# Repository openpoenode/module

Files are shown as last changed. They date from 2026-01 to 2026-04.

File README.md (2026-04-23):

# Technical Specifications

## Core Components

| Component | |
|---|---|
| MCU | ESP32-D0WD-V3 |
| Flash | Winbond SPI 128MBit W25Q128JVP |
| RAM | APMemory 64MBit APS6404L-3SQR-SN |
| Ethernet PHY | SMSC LAN8720A |
| PoE 802.3af Controller | TI TPS23753 |
| eFuse | TI TPS259520DSGR |

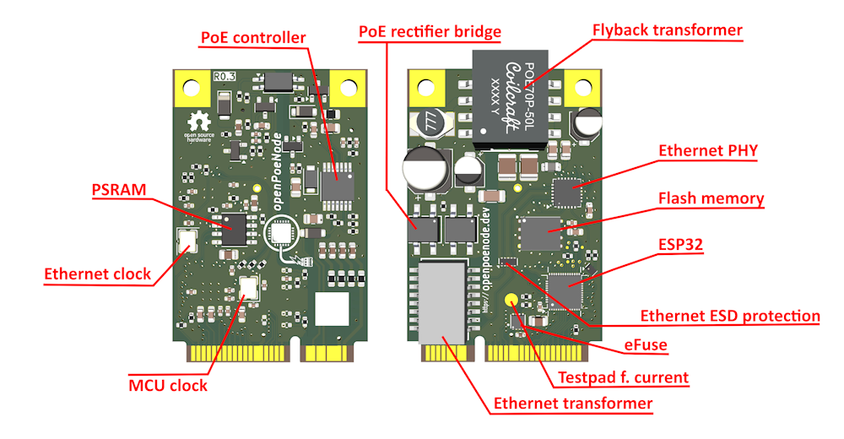
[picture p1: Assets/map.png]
ModuleMap


### Flash Memory

Any standard, pin-compatible SPI NOR flash in a WSON-8 6x5 mm package can be used. Common options are the 32MBit and 64MBit chips from the same line of Winbond flash memories.

### PSRAM

Installing a PSRAM chip is optional, the module will work just fine without the PSRAM IC populated. While any pin-compatible PSRAM chip can be installed, any amount over 32Mbit cannot be addressed by the ESP32 MCU.

### eFuse

- The digital power domain (MCU power supply input) is protected by a latch-off type eFuse. It disconnects supply at V<sub>in</sub> > 3.8V or I<sub>in</sub> > 1.04A.
- The module exposes a test pad for measuring the supply current drawn by the module's digital domain components:
  - I<sub>in</sub> = 1.81 x V<sub>test</sub>
  - V<sub>test</sub> is measured against digital ground

## Goldfinger Connector

The module exposes several signals of its components through a goldfinger connector:

### GPIOs

| GPIO | free | limited | input-only |
|---|---|---|---|
| 2 | | X | |
| 4 | | X | |
| 5 | | X | |
| 12 | | X | |
| 13 | X | | |
| 14 | X | | |
| 15 | | X | |
| 18 | X | | |
| 23 | X | | |
| 32 | X | | |
| 33 | X | | |
| 34 | | | X |
| 35 | | | X |
| 36 | | | X |
| 37 | | | X |
| 38 | | | X |
| 39 | | | X |

GPIOs marked as "limited" have a boot-strapping function and/or a fixed pull-up/pull-down in place.

3 output-capable GPIOs have to be assigned for Ethernet PHY control.

### Ethernet Interface

- Analog (2 differential data pairs, 2x center taps power input)
- 2 Indicator LEDs (Link/Activity, Speed)
- Bob-Smith-Termination
- Digital interface (Enable/Reset, MDC, MDIO)

### Power Supply / Conversion

- High Voltage (PoE domain)
  - External power adapter input, 36V < V<sub>in</sub> < 54V
  - Direct PoE power output for additional DC/DC converters (maximum power draw limited to 802.3af level)
- Low Voltage (Isolated domain)
  - DC/DC converter V<sub>out</sub> = 5V (3.3V optional)
  - I<sub>out,max</sub> = 1.4A (5V) or 2.1A (3.3V)
  - 7W max. output
- Digital domain
  - MCU power supply input (external 3.3V supply required)
  - I<sub>supply,avg</sub> < 500mA (soft limit)
  - I<sub>supply,lim</sub> = 1.04A (latch-off limit)
  - I<sub>supply,idle</sub> = ~150mA (idle supply current - including flash, RAM, 100MBit connected Ethernet, Link/Speed indicators on)

### Programming Interface

- ESP32 UART
- MCU Reset
- GPIO0 (boot strapping only, no direct connection)

## Physical

- Standard Mini-PCIe goldfinger connector, 52 pins
- FR4 1.00 mm base material, 6 layers
- Size: 45 x 30 x 14.5 mm
- Weight: 12g

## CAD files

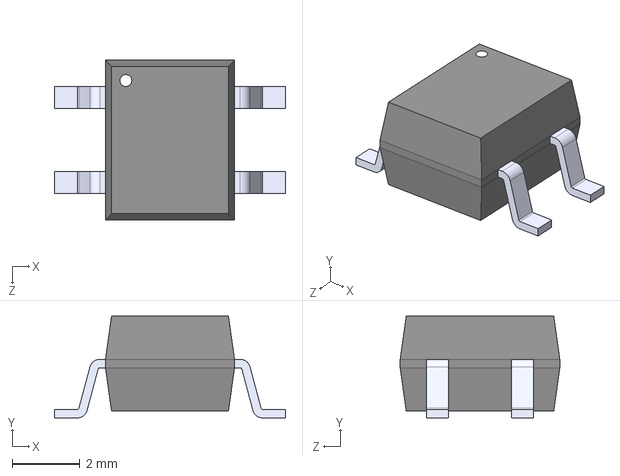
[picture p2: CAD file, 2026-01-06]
3D/HD01-T.STEP
6.80 x 3.00 x 4.70 mm

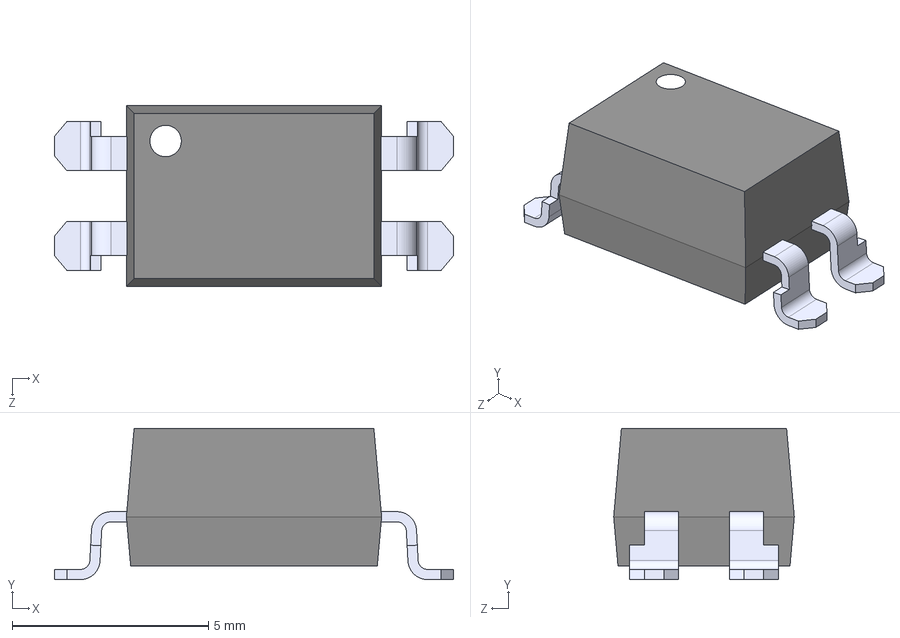
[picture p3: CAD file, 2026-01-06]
3D/FOD817AS.step
10.2 x 3.85 x 4.60 mm

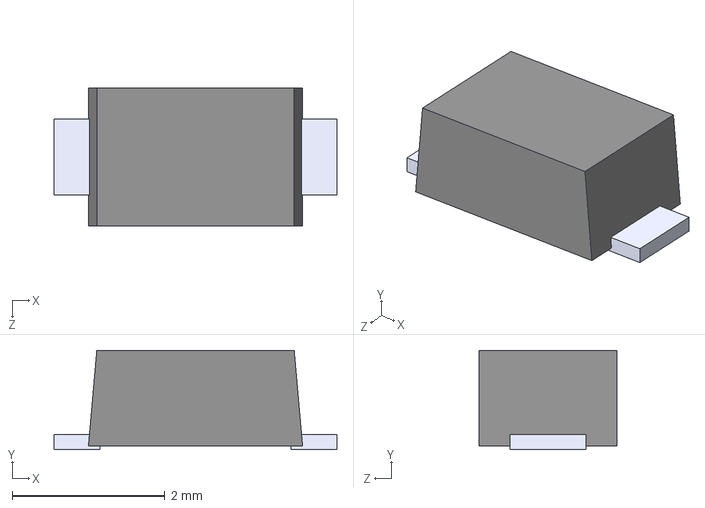
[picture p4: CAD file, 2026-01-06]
3D/USL1D.STEP
3.70 x 1.30 x 1.80 mm

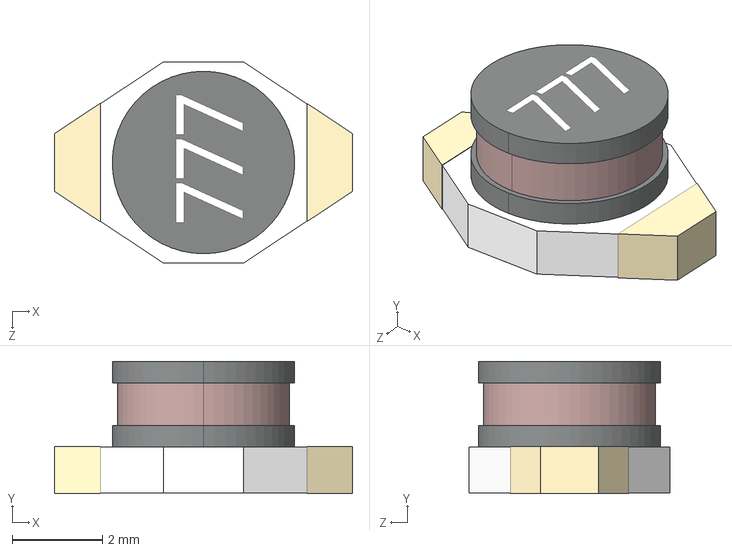
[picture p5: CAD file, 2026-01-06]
3D/Coilcraft-DO1608C.STEP
6.60 x 2.93 x 4.45 mm

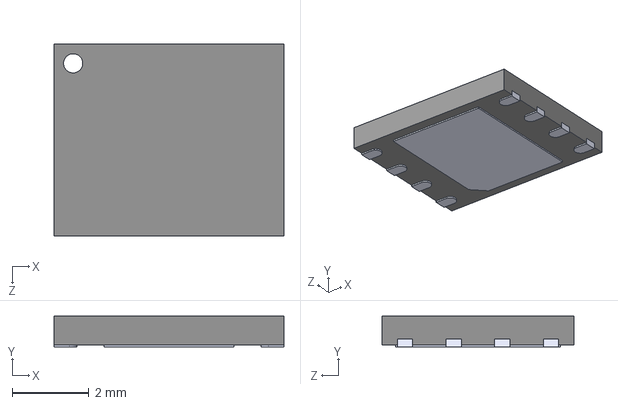
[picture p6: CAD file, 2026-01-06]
3D/W25Q32JVZPIQ.step
6.00 x 0.8 x 5.00 mm

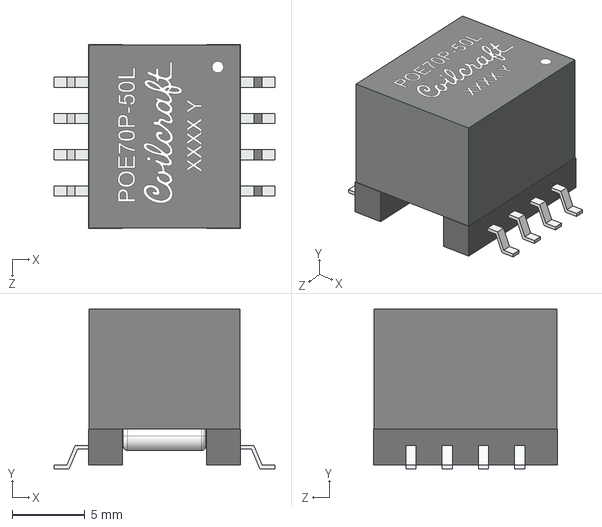
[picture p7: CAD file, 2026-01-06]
3D/Coilcraft-POE70P-50L.STEP
15.2 x 11.0 x 12.7 mm

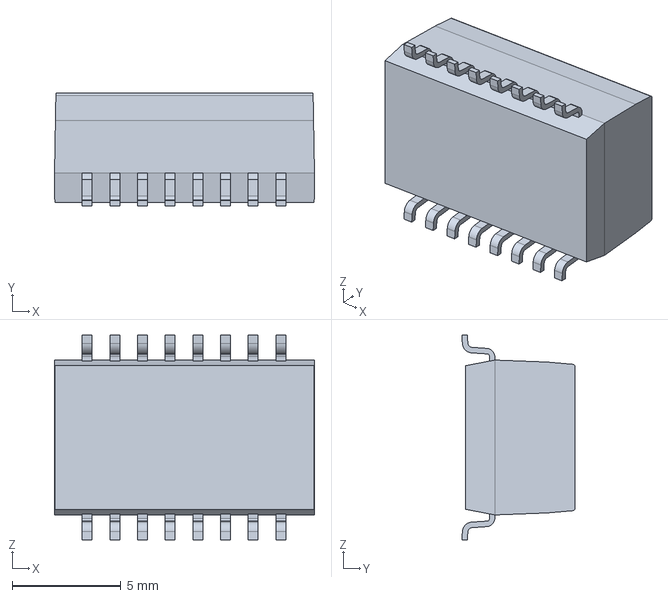
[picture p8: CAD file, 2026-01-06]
3D/S558-5500-25-F.stp
11.9 x 5.21 x 9.40 mm

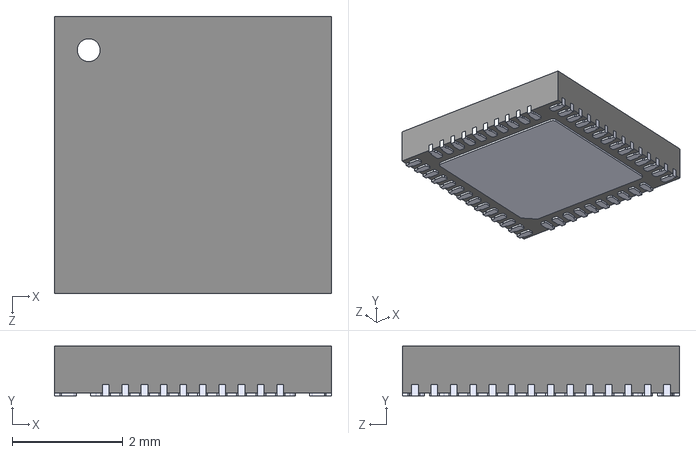
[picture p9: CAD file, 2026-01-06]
3D/ESP32-D0WD.step
5.00 x 0.9 x 5.00 mm

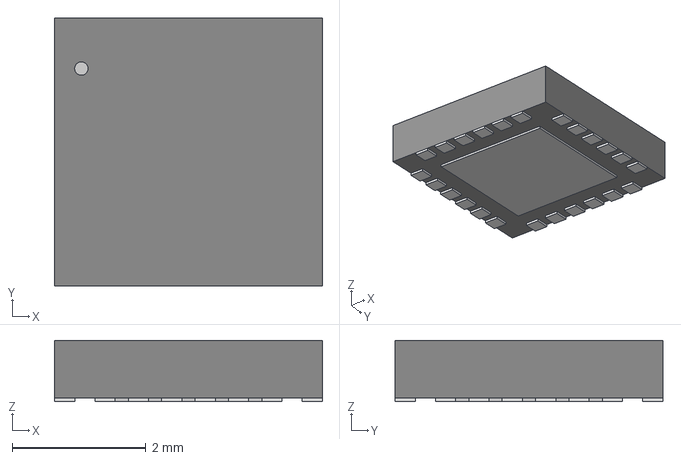
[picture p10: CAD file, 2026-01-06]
3D/QFN24-6X6_MC_MCH.step
4.01 x 4.01 x 0.917 mm

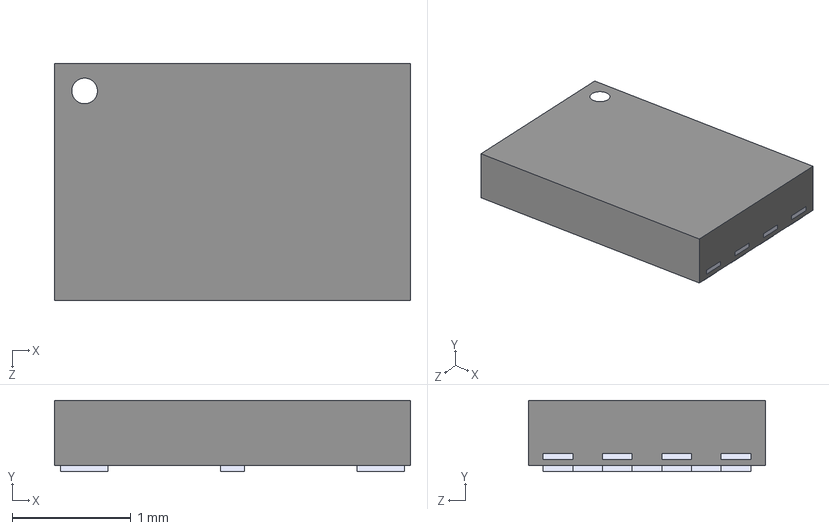
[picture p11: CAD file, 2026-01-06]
3D/USON8.STEP
3.00 x 0.6 x 2.00 mm

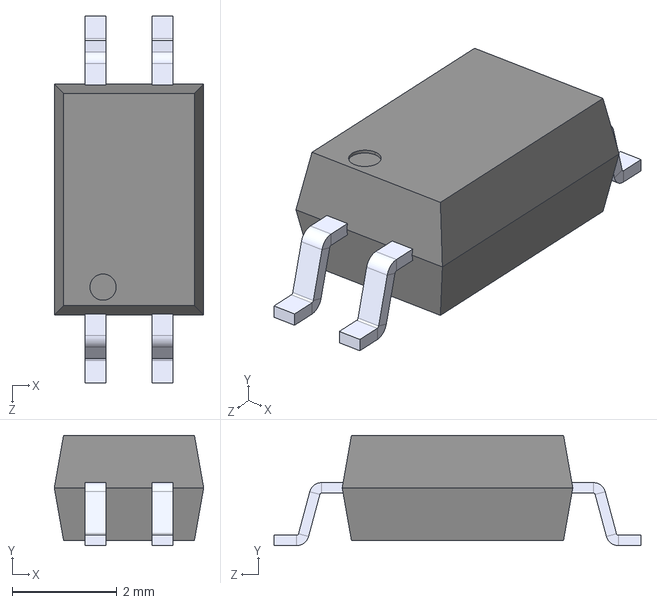
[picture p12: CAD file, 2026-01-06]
3D/VOS617A-8T.STEP
2.85 x 2.10 x 7.00 mm

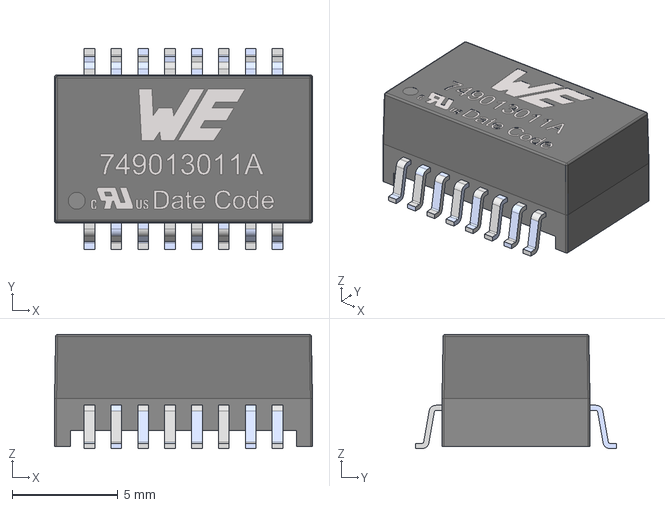
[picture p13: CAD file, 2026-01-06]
3D/749013011A.stp
12.2 x 9.52 x 5.40 mm
housing
Pin

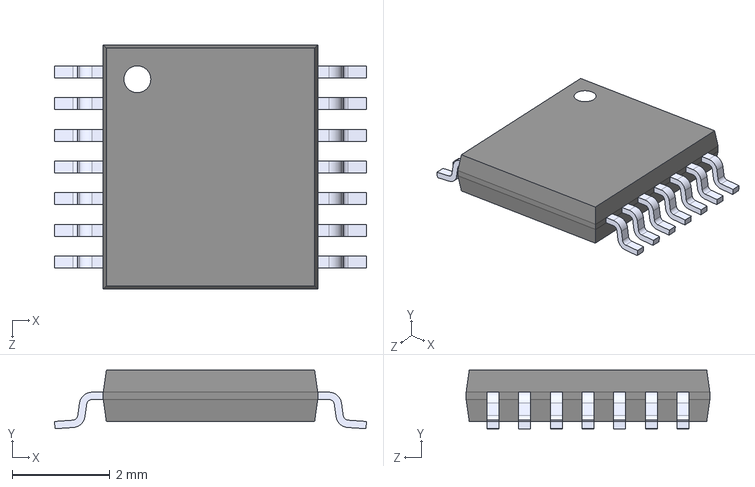
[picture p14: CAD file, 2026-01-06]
3D/TPS23753APW.step
6.40 x 1.20 x 5.00 mm

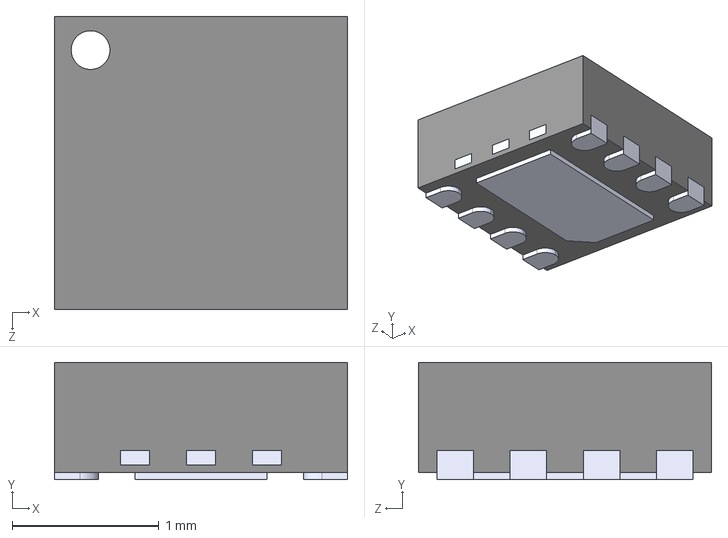
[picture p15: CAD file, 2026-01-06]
3D/TPS259520DSGR.step
2.00 x 0.8 x 2.00 mm

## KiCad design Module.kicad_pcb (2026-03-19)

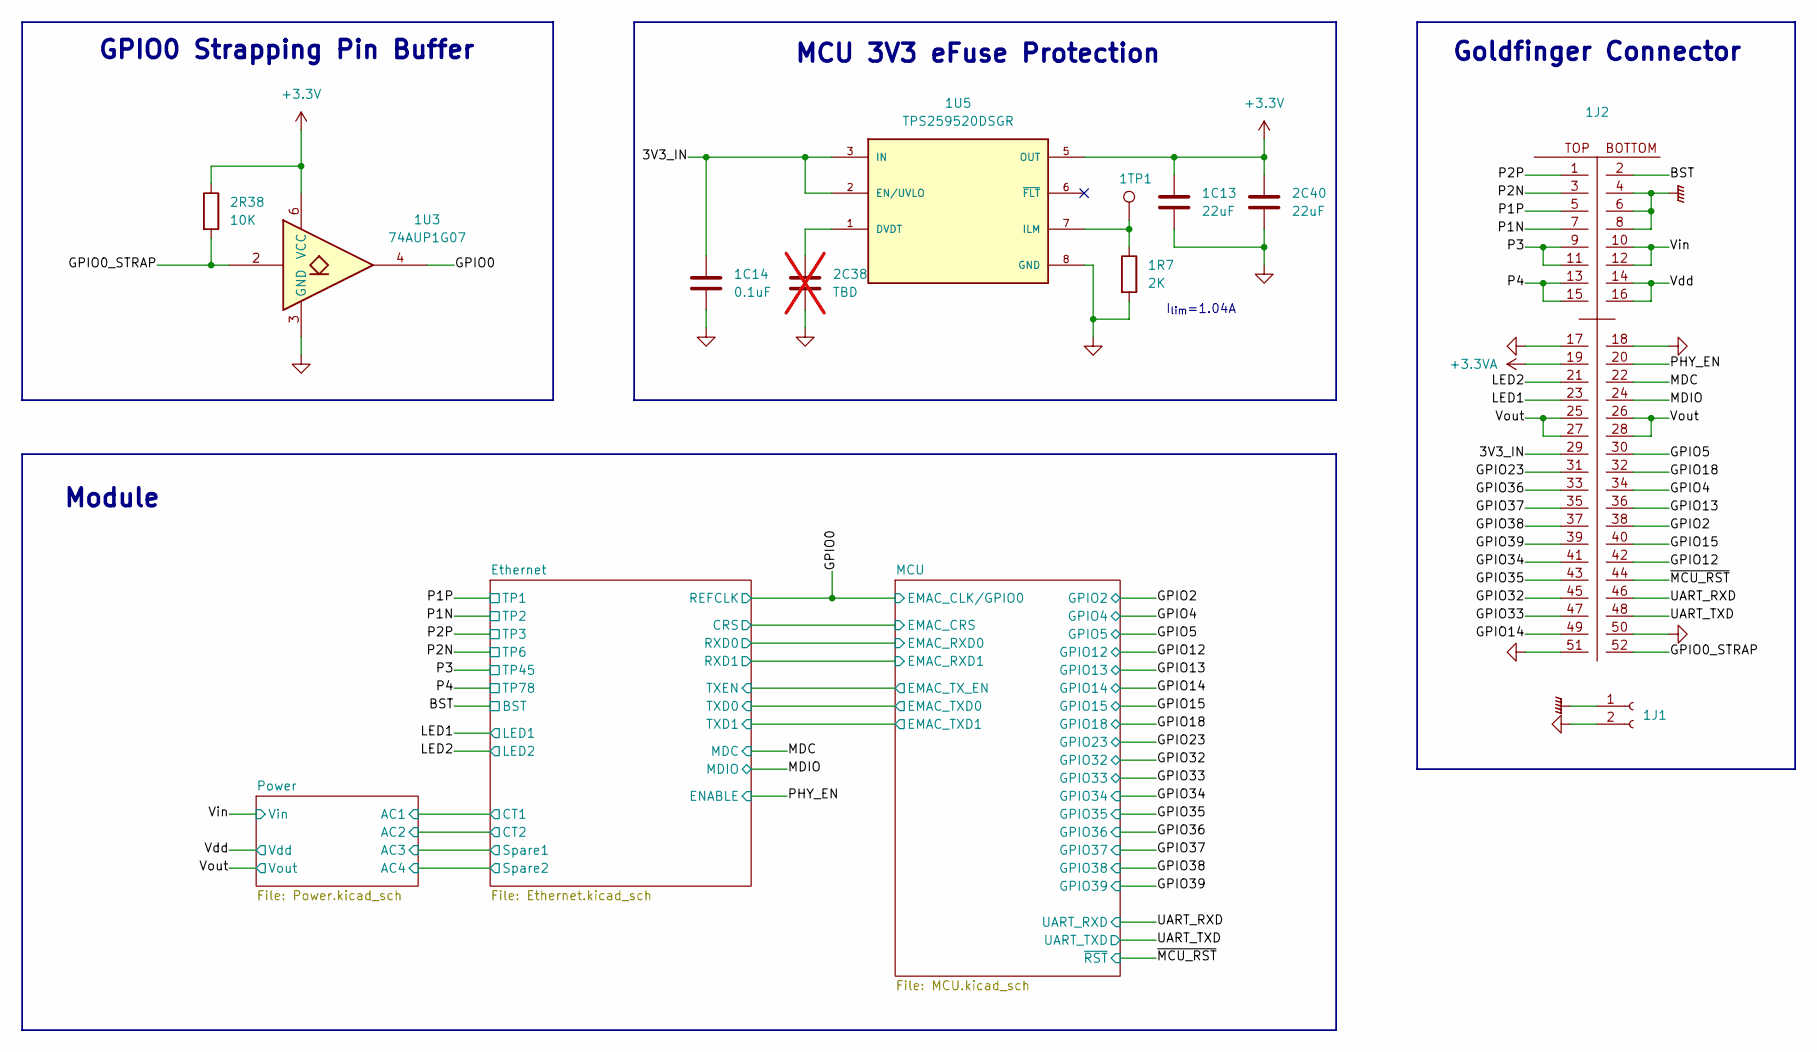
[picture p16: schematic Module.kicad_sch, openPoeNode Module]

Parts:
1C13, 2C40: 22uF; C_0805_2012Metric; MOUSER# 81-GRM21BZ71A226ME5L
1C14: 0.1uF; C_0402_1005Metric; MOUSER# 81-GCM155R71H104KE2J
1J1: HOLDDOWN; mPCIe-Hold
1J2: Mini-PCIe
1R7: 2K; R_0402_1005Metric; MOUSER# 71-CRCW0402-2.0K-E3
1TP1: TestPoint; TestPoint_Pad_D2.0mm
1U3: 74AUP1G07; Texas_USON-6_1x1.45mm_P0.5mm_SMD; MOUSER# 595-SN74AUP1G07DRYR
1U5: TPS259520DSGR; SON50P200X200X80-9N; MOUSER# 595-TPS259520DSGR
2C38: TBD; C_0402_1005Metric; not fitted
2R38: 10K; R_0402_1005Metric; MOUSER# 603-RE0402FRE0710KL

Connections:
+3.3V: 1C13.1, 1U3.6 (VCC), 1U5.5 (OUT), 2C40.1, 2R38.1; also elsewhere on the board
+3.3VA: 1J2.19; also elsewhere on the board
/3V3_IN: 1C14.2, 1J2.29, 1U5.2 (EN/UVLO), 1U5.3 (IN), 1U5.4 (IN)
/BST: 1J2.2; also elsewhere on the board
/GPIO0: 1U3.4; also elsewhere on the board
/GPIO0_STRAP: 1J2.52, 1U3.2, 2R38.2
/GPIO2: 1J2.38; also elsewhere on the board
/GPIO4: 1J2.34; also elsewhere on the board
/GPIO5: 1J2.30; also elsewhere on the board
/GPIO12: 1J2.42; also elsewhere on the board
/GPIO13: 1J2.36; also elsewhere on the board
/GPIO14: 1J2.49; also elsewhere on the board
/GPIO15: 1J2.40; also elsewhere on the board
/GPIO18: 1J2.32; also elsewhere on the board
/GPIO23: 1J2.31; also elsewhere on the board
/GPIO32: 1J2.45; also elsewhere on the board
/GPIO33: 1J2.47; also elsewhere on the board
/GPIO34: 1J2.41; also elsewhere on the board
/GPIO35: 1J2.43; also elsewhere on the board
/GPIO36: 1J2.33; also elsewhere on the board
/GPIO37: 1J2.35; also elsewhere on the board
/GPIO38: 1J2.37; also elsewhere on the board
/GPIO39: 1J2.39; also elsewhere on the board
/LED1: 1J2.23; also elsewhere on the board
/LED2: 1J2.21; also elsewhere on the board
/MDC: 1J2.22; also elsewhere on the board
/MDIO: 1J2.24; also elsewhere on the board
/P1N: 1J2.7; also elsewhere on the board
/P1P: 1J2.5; also elsewhere on the board
/P2N: 1J2.3; also elsewhere on the board
/P2P: 1J2.1; also elsewhere on the board
/P3: 1J2.9, 1J2.11; also elsewhere on the board
/P4: 1J2.13, 1J2.15; also elsewhere on the board
/PHY_EN: 1J2.20; also elsewhere on the board
/UART_RXD: 1J2.46; also elsewhere on the board
/UART_TXD: 1J2.48; also elsewhere on the board
/Vdd: 1J2.14, 1J2.16; also elsewhere on the board
/Vin: 1J2.10, 1J2.12; also elsewhere on the board
/Vout: 1J2.25, 1J2.26, 1J2.27, 1J2.28; also elsewhere on the board
/~MCU_RST: 1J2.44; also elsewhere on the board
GND: 1C13.2, 1C14.1, 1J1.2, 1J2.17, 1J2.18, 1J2.50, 1J2.51, 1R7.2, 1U3.3 (GND), 1U5.8 (GND), 1U5.9 (GND), 2C38.2, 2C40.2; also elsewhere on the board
GNDPWR: 1J1.1, 1J2.4, 1J2.6, 1J2.8; also elsewhere on the board
unnamed: 1U5.1 (DVDT), 2C38.1
unnamed: 1R7.1, 1TP1.1, 1U5.7 (ILM)

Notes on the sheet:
Goldfinger Connector
I_{lim}=1.04A
MCU 3V3 eFuse Protection
GPIO0 Strapping Pin Buffer
Module

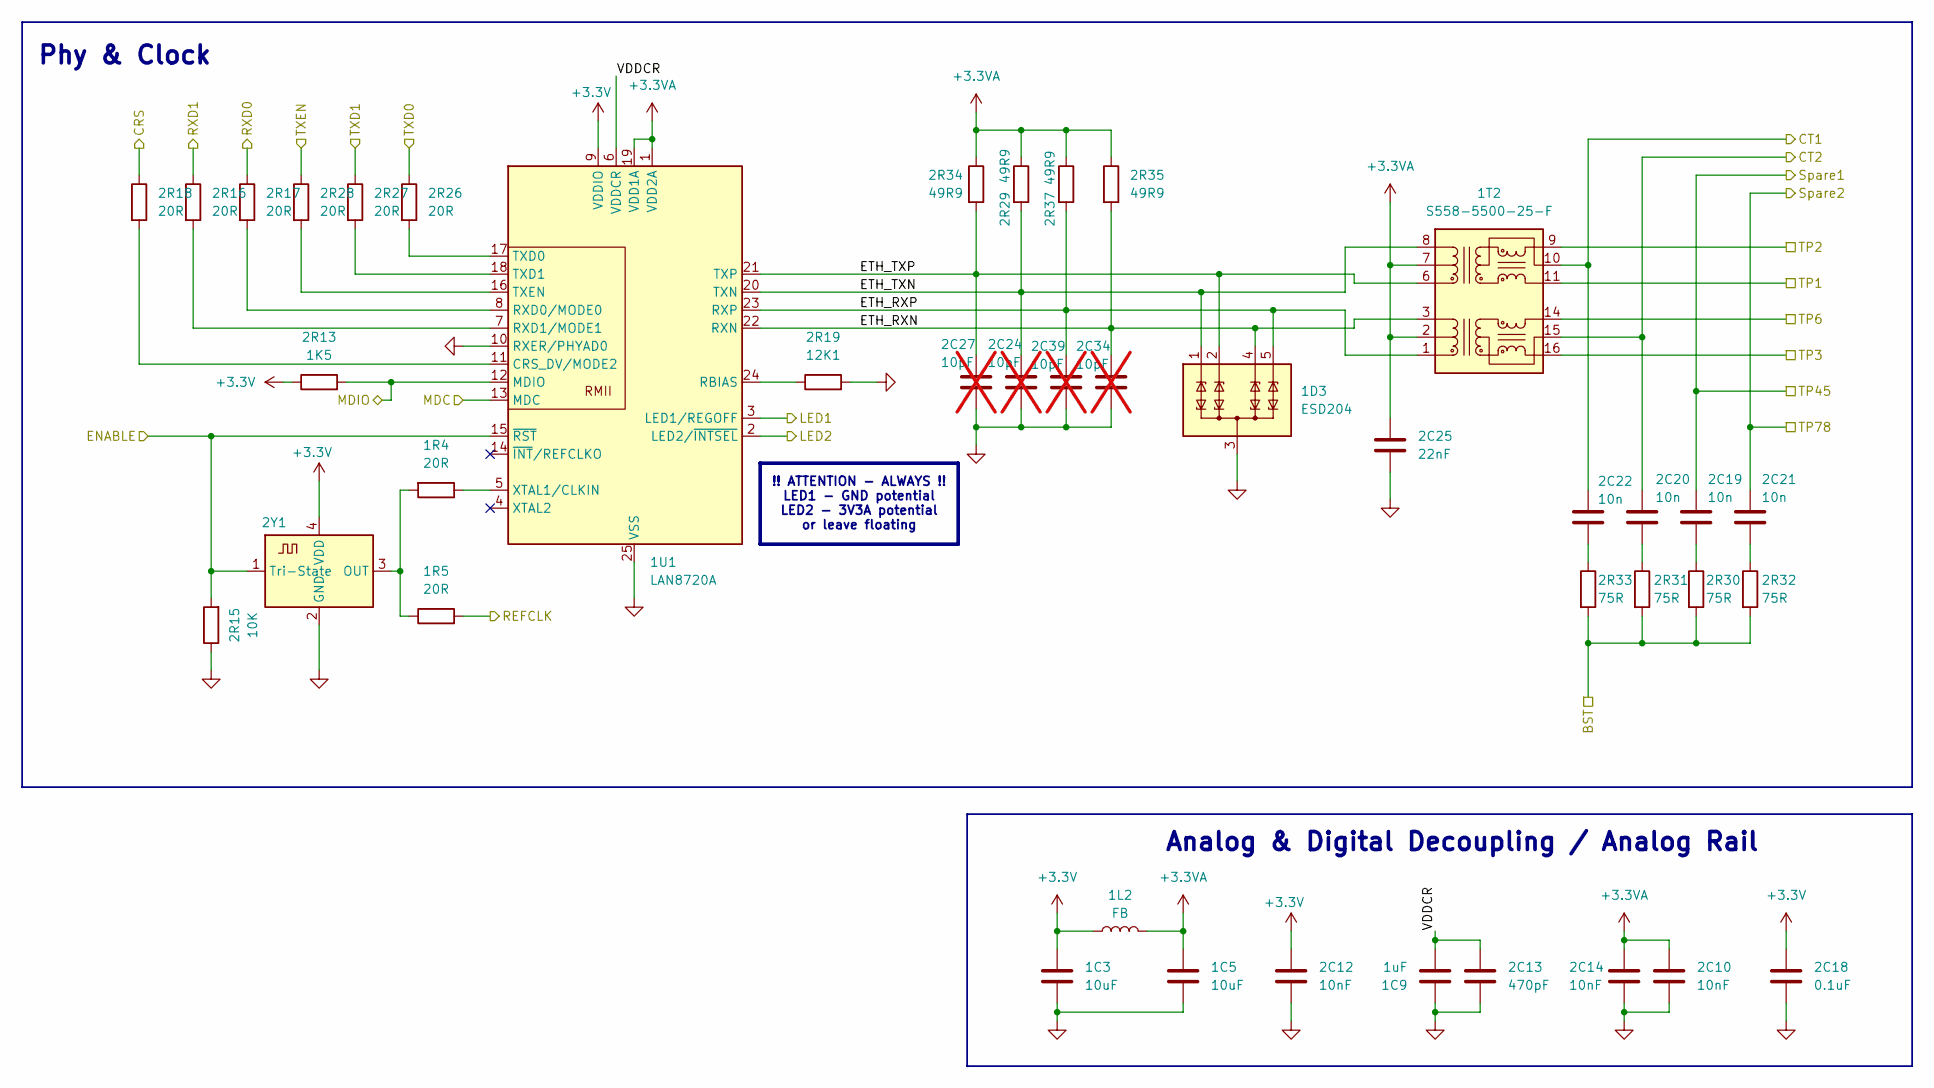
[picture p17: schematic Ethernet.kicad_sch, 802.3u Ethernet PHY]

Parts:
1C3, 1C5: 10uF; C_0805_2012Metric; MOUSER# 81-GRM21BR71A106MA3L
1C9: 1uF; C_0603_1608Metric; MOUSER# 963-EMK107B7105KA-T
1D3: ESD204; USON-10_2.5x1.0mm_P0.5mm; MOUSER# 595-ESD204DQAR
1L2: FB; L_0805_2012Metric; MOUSER#(alt) 603-BBPY201209121Y00
1R4, 1R5, 2R16, 2R17, 2R18, 2R26, 2R27, 2R28: 20R; R_0402_1005Metric; MOUSER# 660-RK73B1ETTP200J
1T2: S558-5500-25-F; MOUSER# 530-S558-5500-25-F
1U1: LAN8720A; QFN-24-1EP_4x4mm_P0.5mm_EP2.5x2.5mm; MOUSER# 579-LAN8720ACPTRABC
2C10, 2C12, 2C14: 10nF; C_0402_1005Metric; MOUSER# 963-EMK105B7103KV-F
2C13: 470pF; C_0402_1005Metric; MOUSER# 791-0402B471K250CT
2C18: 0.1uF; C_0402_1005Metric; MOUSER# 81-GCM155R71H104KE2J
2C19, 2C20, 2C21, 2C22: 10n; C_0603_1608Metric; MOUSER# 603-CC0603JRX70BB103
2C24, 2C27, 2C34, 2C39: 10pF; C_0402_1005Metric; MOUSER# 963-UMK105CG100DV-F; not fitted
2C25: 22nF; C_0402_1005Metric; MOUSER# 81-GRM155R71H223KA2J
2R13: 1K5; R_0402_1005Metric; MOUSER# 667-ERJ-2RKF1501X
2R15: 10K; R_0402_1005Metric; MOUSER# 603-RE0402FRE0710KL
2R19: 12K1; R_0402_1005Metric; MOUSER# 603-RT0402FRE0712K1L
2R29, 2R34, 2R35, 2R37: 49R9; R_0402_1005Metric; MOUSER# 660-RK73H1ETTP49R9F
2R30, 2R31, 2R32, 2R33: 75R; R_0603_1608Metric; MOUSER# 660-SG73S1JTTD75R0F
2Y1: ECS-2333-500-BN-TR; Crystal_SMD_3225-4Pin_3.2x2.5mm; MOUSER# 520-ECS-2333-500-BNT

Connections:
+3.3V: 1C3.1, 1L2.1, 1U1.9 (VDDIO), 2C12.2, 2C18.2, 2R13.1, 2Y1.4 (VDD); also elsewhere on the board
+3.3VA: 1C5.1, 1L2.2, 1T2.2 (C_TD), 1T2.7 (C_RD), 1U1.1 (VDD2A), 1U1.19 (VDD1A), 2C10.2, 2C14.2, 2C25.1, 2R29.1, 2R34.1, 2R35.1, 2R37.1; also elsewhere on the board
/BST: 2R30.2, 2R31.2, 2R32.2, 2R33.2; also elsewhere on the board
/Ethernet/CRS: 2R18.1; also elsewhere on the board
/Ethernet/CT1: 1T2.10 (C_RX), 2C22.1; also elsewhere on the board
/Ethernet/CT2: 1T2.15 (C_TX), 2C20.1; also elsewhere on the board
/Ethernet/ETH_RXN: 1D3.4 (TVS3), 1D3.7 (TVS3), 1T2.3 (TD-), 1U1.22 (RXN), 2C34.1, 2R35.2
/Ethernet/ETH_RXP: 1D3.5 (TVS4), 1D3.6 (TVS4), 1T2.1 (TD+), 1U1.23 (RXP), 2C39.1, 2R37.2
/Ethernet/ETH_TXN: 1D3.1 (TVS1), 1D3.10 (TVS1), 1T2.8 (RD-), 1U1.20 (TXN), 2C24.1, 2R29.2
/Ethernet/ETH_TXP: 1D3.2 (TVS2), 1D3.9 (TVS2), 1T2.6 (RD+), 1U1.21 (TXP), 2C27.1, 2R34.2
/Ethernet/RXD0: 2R17.1; also elsewhere on the board
/Ethernet/RXD1: 2R16.1; also elsewhere on the board
/Ethernet/TXD0: 2R26.1; also elsewhere on the board
/Ethernet/TXD1: 2R27.1; also elsewhere on the board
/Ethernet/TXEN: 2R28.1; also elsewhere on the board
/Ethernet/VDDCR: 1C9.1, 1U1.6 (VDDCR), 2C13.1
/GPIO0: 1R5.2; also elsewhere on the board
/LED1: 1U1.3 (LED1/REGOFF); also elsewhere on the board
/LED2: 1U1.2 (LED2/~INTSEL); also elsewhere on the board
/MDC: 1U1.13 (MDC); also elsewhere on the board
/MDIO: 1U1.12 (MDIO), 2R13.2; also elsewhere on the board
/P1N: 1T2.9 (RX-); also elsewhere on the board
/P1P: 1T2.11 (RX+); also elsewhere on the board
/P2N: 1T2.14 (TX-); also elsewhere on the board
/P2P: 1T2.16 (TX+); also elsewhere on the board
/P3: 2C19.1; also elsewhere on the board
/P4: 2C21.1; also elsewhere on the board
/PHY_EN: 1U1.15 (~RST), 2R15.2, 2Y1.1 (Tri-State); also elsewhere on the board
GND: 1C3.2, 1C5.2, 1C9.2, 1D3.3 (COM), 1D3.8 (COM), 1U1.10 (RXER/PHYAD0), 1U1.25 (VSS), 2C10.1, 2C12.1, 2C13.2, 2C14.1, 2C18.1, 2C24.2, 2C25.2, 2C27.2, 2C34.2, 2C39.2, 2R15.1, 2R19.2, 2Y1.2 (GND); also elsewhere on the board
unnamed: 1U1.11 (CRS_DV/MODE2), 2R18.2
unnamed: 1U1.24 (RBIAS), 2R19.1
unnamed: 1U1.8 (RXD0/MODE0), 2R17.2
unnamed: 1U1.7 (RXD1/MODE1), 2R16.2
unnamed: 1U1.17 (TXD0), 2R26.2
unnamed: 1U1.18 (TXD1), 2R27.2
unnamed: 1U1.16 (TXEN), 2R28.2
unnamed: 1R4.1, 1U1.5 (XTAL1/CLKIN)
unnamed: 2C19.2, 2R30.1
unnamed: 2C20.2, 2R31.1
unnamed: 2C21.2, 2R32.1
unnamed: 2C22.2, 2R33.1
unnamed: 1R4.2, 1R5.1, 2Y1.3 (OUT)

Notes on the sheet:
Phy & Clock
!! ATTENTION - ALWAYS !! LED1 - GND potential LED2 - 3V3A potential or leave floating
Analog & Digital Decoupling / Analog Rail

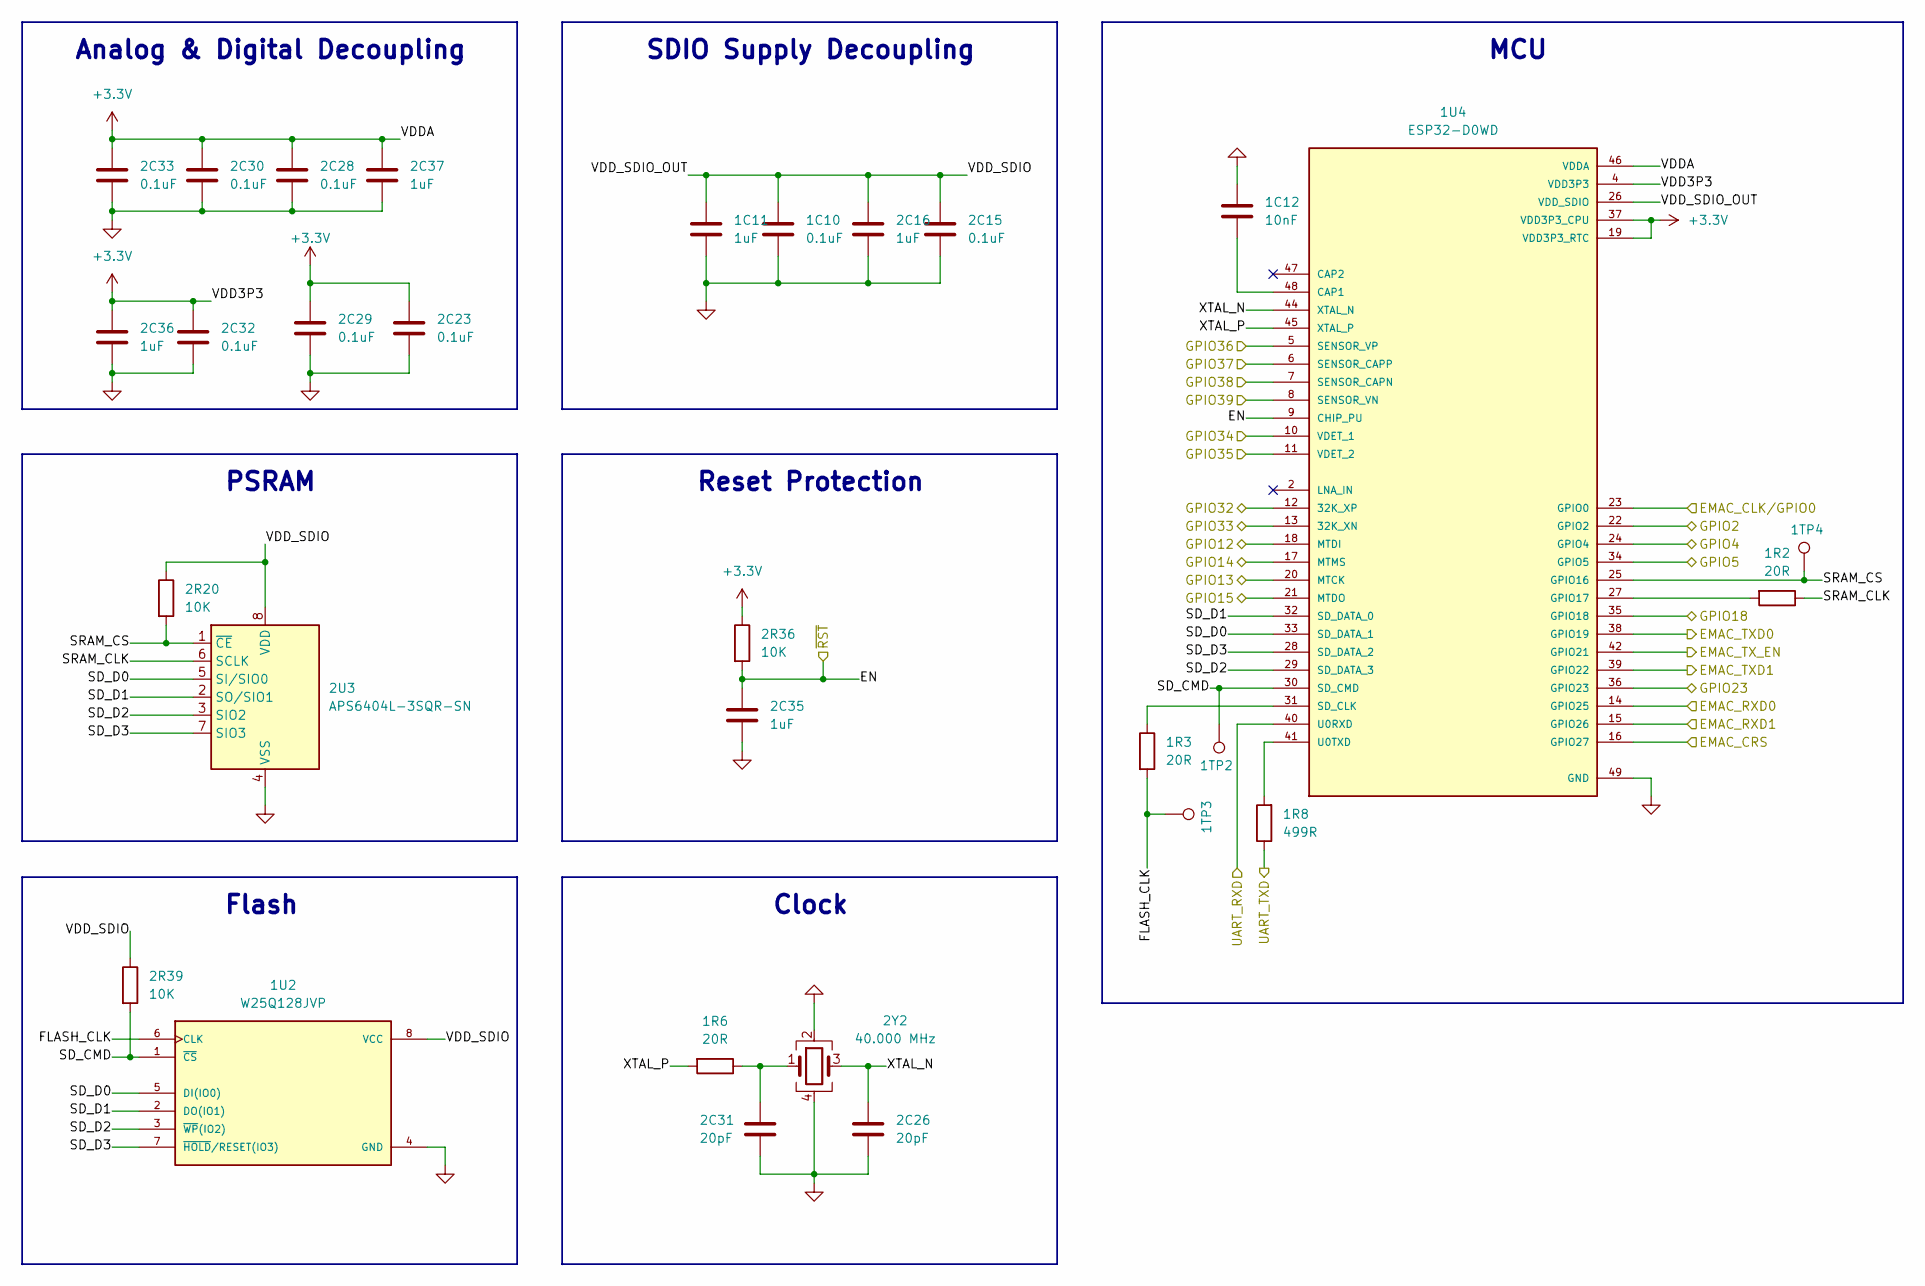
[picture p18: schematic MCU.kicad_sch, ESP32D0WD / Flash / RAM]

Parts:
1C10, 2C15, 2C23, 2C28, 2C29, 2C30, 2C32, 2C33: 0.1uF; C_0402_1005Metric; MOUSER# 81-GCM155R71H104KE2J
1C11, 2C16, 2C35, 2C36, 2C37: 1uF; C_0603_1608Metric; MOUSER# 963-EMK107B7105KA-T
1C12: 10nF; C_0402_1005Metric; MOUSER# 963-EMK105B7103KV-F
1R2, 1R3, 1R6: 20R; R_0402_1005Metric; MOUSER# 660-RK73B1ETTP200J
1R8: 499R; R_0402_1005Metric; MOUSER# 791-RMC1/16SK4990FTH
1TP2, 1TP3, 1TP4: TestPoint; TestPoint_Pad_D1.0mm
1U2: W25Q128JVP; SON127P600X500X80-9N; MOUSER# 454-W25Q128JVPIM
1U4: ESP32-D0WD; QFN-48-1EP_5x5mm_P0.35mm_EP3.7x3.7mm; MOUSER# 356-ESP32-D0WD-V3
2C26, 2C31: 20pF; C_0402_1005Metric; MOUSER# 187-CL05C200JB51PNC
2R20, 2R36, 2R39: 10K; R_0402_1005Metric; MOUSER# 603-RE0402FRE0710KL
2U3: APS6404L-3SQR-SN; SOIC-8_3.9x4.9mm_P1.27mm; MOUSER# 878-APS6404L-3SQR-SN
2Y2: 40.000 MHz; Crystal_SMD_3225-4Pin_3.2x2.5mm; MOUSER# 815-M840000MHZ12B1UT

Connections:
+3.3V: 1U4.1 (VDDA), 1U4.3 (VDD3P3), 1U4.4 (VDD3P3), 1U4.19 (VDD3P3_RTC), 1U4.37 (VDD3P3_CPU), 1U4.43 (VDDA), 1U4.46 (VDDA), 2C23.2, 2C28.2, 2C29.2, 2C30.2, 2C32.2, 2C33.2, 2C36.2, 2C37.2, 2R36.1; also elsewhere on the board
/Ethernet/CRS: 1U4.16 (GPIO27); also elsewhere on the board
/Ethernet/RXD0: 1U4.14 (GPIO25); also elsewhere on the board
/Ethernet/RXD1: 1U4.15 (GPIO26); also elsewhere on the board
/Ethernet/TXD0: 1U4.38 (GPIO19); also elsewhere on the board
/Ethernet/TXD1: 1U4.39 (GPIO22); also elsewhere on the board
/Ethernet/TXEN: 1U4.42 (GPIO21); also elsewhere on the board
/GPIO0: 1U4.23 (GPIO0); also elsewhere on the board
/GPIO2: 1U4.22 (GPIO2); also elsewhere on the board
/GPIO4: 1U4.24 (GPIO4); also elsewhere on the board
/GPIO5: 1U4.34 (GPIO5); also elsewhere on the board
/GPIO12: 1U4.18 (MTDI); also elsewhere on the board
/GPIO13: 1U4.20 (MTCK); also elsewhere on the board
/GPIO14: 1U4.17 (MTMS); also elsewhere on the board
/GPIO15: 1U4.21 (MTDO); also elsewhere on the board
/GPIO18: 1U4.35 (GPIO18); also elsewhere on the board
/GPIO23: 1U4.36 (GPIO23); also elsewhere on the board
/GPIO32: 1U4.12 (32K_XP); also elsewhere on the board
/GPIO33: 1U4.13 (32K_XN); also elsewhere on the board
/GPIO34: 1U4.10 (VDET_1); also elsewhere on the board
/GPIO35: 1U4.11 (VDET_2); also elsewhere on the board
/GPIO36: 1U4.5 (SENSOR_VP); also elsewhere on the board
/GPIO37: 1U4.6 (SENSOR_CAPP); also elsewhere on the board
/GPIO38: 1U4.7 (SENSOR_CAPN); also elsewhere on the board
/GPIO39: 1U4.8 (SENSOR_VN); also elsewhere on the board
/MCU/FLASH_CLK: 1R3.2, 1TP3.1, 1U2.6 (CLK)
/MCU/SD_CMD: 1TP2.1, 1U2.1 (~CS), 1U4.30 (SD_CMD), 2R39.2
/MCU/SD_D0: 1U2.5 (DI(IO0)), 1U4.33 (SD_DATA_1), 2U3.5 (SI/SIO0)
/MCU/SD_D1: 1U2.2 (DO(IO1)), 1U4.32 (SD_DATA_0), 2U3.2 (SO/SIO1)
/MCU/SD_D2: 1U2.3 (~WP(IO2)), 1U4.29 (SD_DATA_3), 2U3.3 (SIO2)
/MCU/SD_D3: 1U2.7 (~HOLD/RESET(IO3)), 1U4.28 (SD_DATA_2), 2U3.7 (SIO3)
/MCU/SRAM_CLK: 1R2.1, 2U3.6 (SCLK)
/MCU/SRAM_CS: 1TP4.1, 1U4.25 (GPIO16), 2R20.2, 2U3.1 (~CE)
/MCU/VDD_SDIO: 1C10.2, 1C11.2, 1U2.8 (VCC), 1U4.26 (VDD_SDIO), 2C15.2, 2C16.2, 2R20.1, 2R39.1, 2U3.8 (VDD)
/MCU/XTAL_N: 1U4.44 (XTAL_N), 2C26.1, 2Y2.3
/MCU/XTAL_P: 1R6.2, 1U4.45 (XTAL_P)
/UART_RXD: 1U4.40 (U0RXD); also elsewhere on the board
/UART_TXD: 1R8.1; also elsewhere on the board
/~MCU_RST: 1U4.9 (CHIP_PU), 2C35.2, 2R36.2; also elsewhere on the board
GND: 1C10.1, 1C11.1, 1C12.2, 1U2.4 (GND), 1U4.49 (GND), 2C15.1, 2C16.1, 2C23.1, 2C26.2, 2C28.1, 2C29.1, 2C30.1, 2C31.2, 2C32.1, 2C33.1, 2C35.1, 2C36.1, 2C37.1, 2U3.4 (VSS), 2Y2.2, 2Y2.4; also elsewhere on the board
unnamed: 1R6.1, 2C31.1, 2Y2.1
unnamed: 1C12.1, 1U4.48 (CAP1)
unnamed: 1R2.2, 1U4.27 (GPIO17)
unnamed: 1R3.1, 1U4.31 (SD_CLK)
unnamed: 1R8.2, 1U4.41 (U0TXD)

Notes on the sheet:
Flash
Reset Protection
MCU
Analog & Digital Decoupling
PSRAM
SDIO Supply Decoupling
Clock

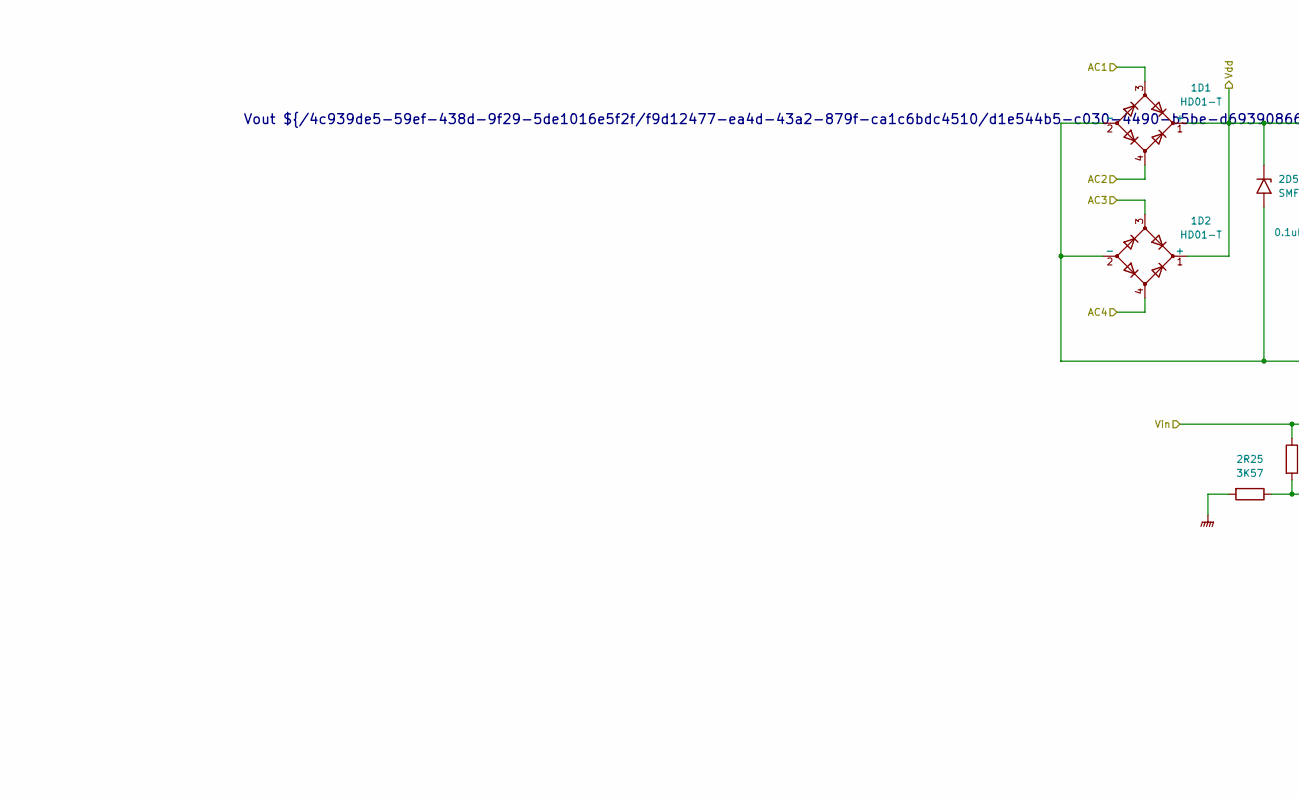
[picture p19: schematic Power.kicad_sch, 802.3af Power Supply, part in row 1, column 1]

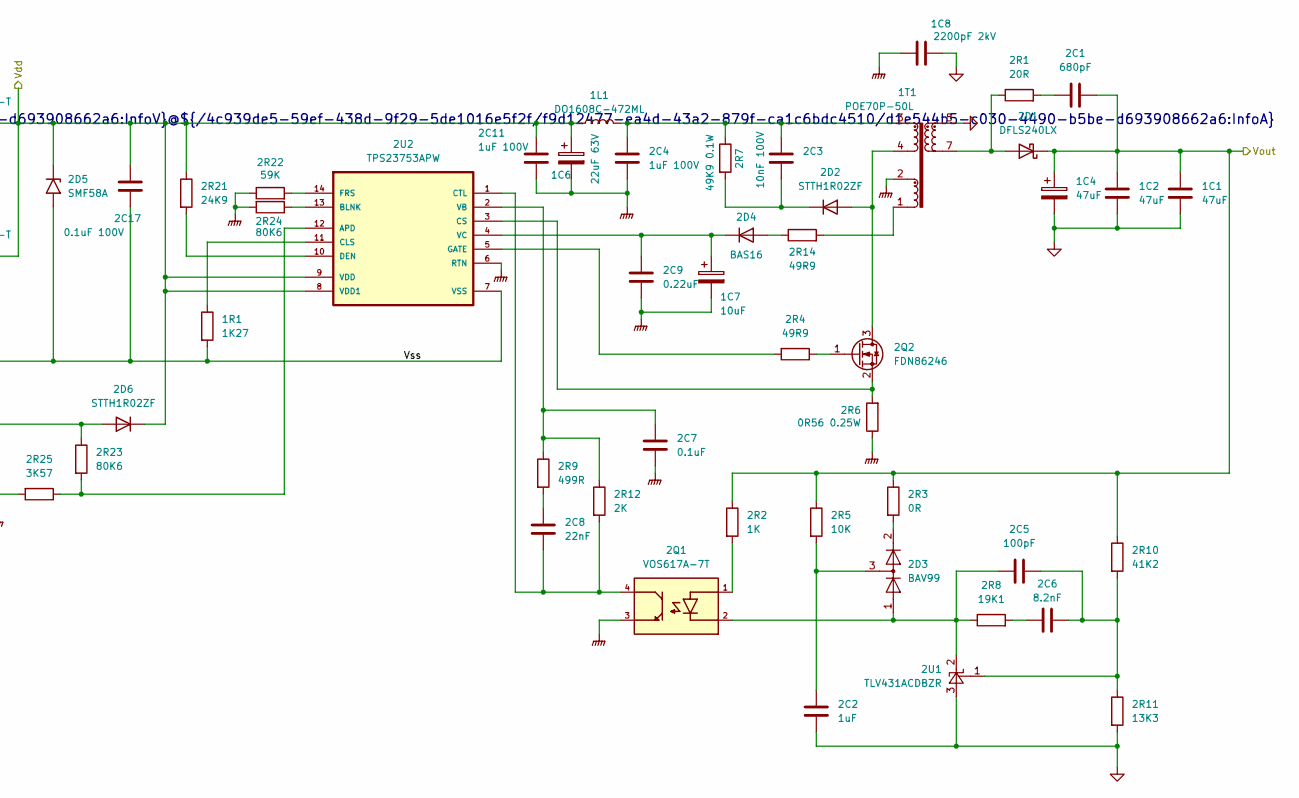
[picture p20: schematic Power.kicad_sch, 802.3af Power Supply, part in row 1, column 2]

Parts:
1C1, 1C2: 47uF; C_1210_3225Metric; MOUSER# 187-CL32B476MPJNNNE
1C4: 47uF; CP_Elec_4x5.8; MOUSER# 667-EEE-FK0J470UR
1C6: 22uF 63V; CP_Elec_6.3x7.7; MOUSER# 667-EEE-FK1J220XP
1C7: 10uF; CP_Elec_4x5.8; MOUSER# 667-EEE-FK1E100R
1C8: 2200pF 2kV; C_1206_3216Metric; MOUSER# 581-1206GC222KAT2A
1D1, 1D2: HD01-T; SO_MiniDipHD01_4P9X4_DIO; MOUSER# 621-HD01-T
1L1: DO1608C-472ML; DO1608C; MOUSER# 994-DO1608C-472MLC
1R1: 1K27; R_0402_1005Metric; MOUSER# 603-RC0402FR-071K27L
1T1: POE70P-50L; POE3070P; MOUSER# 994-POE70P-50LD
2C1: 680pF; C_0603_1608Metric; MOUSER# 581-06035C681K4Z2A
2C2: 1uF; C_0603_1608Metric; MOUSER# 963-EMK107B7105KA-T
2C3: 10nF 100V; C_0603_1608Metric; MOUSER# 581-06031C103K4T2A
2C4, 2C11: 1uF 100V; C_0805_2012Metric; MOUSER# 963-HMR212CC7105KG-T
2C5: 100pF; C_0402_1005Metric; MOUSER# 187-CL05C101JB5NNND
2C6: 8.2nF; C_0402_1005Metric; MOUSER# 81-GCM155R71H822KA5J
2C7: 0.1uF; C_0402_1005Metric; MOUSER# 81-GCM155R71H104KE2J
2C8: 22nF; C_0402_1005Metric; MOUSER# 81-GRM155R71H223KA2J
2C9: 0.22uF; C_0402_1005Metric; MOUSER# 963-TMK105B7224KV-FR
2C17: 0.1uF 100V; C_0805_2012Metric; MOUSER# 187-CL21B104KCFSFNG
2D1: DFLS240LX; D_PowerDI-123; MOUSER# 621-DFLS240LX-7
2D2, 2D6: STTH1R02ZF; D_SOD-123F; MOUSER# 511-STTH1R02ZF
2D3: BAV99; SOT-23; MOUSER# 637-BAV99
2D4: BAS16; SOT-23; MOUSER# 833-BAS16-TP
2D5: SMF58A; P37_SOD-123FL; MOUSER# 637-SMF58A
2Q1: VOS617A-7T; SSOP-4_4.4x2.6mm_P1.27mm; MOUSER# 78-VOS617A-7T
2Q2: FDN86246; SOT-23; MOUSER# 512-FDN86246
2R1: 20R; R_0402_1005Metric; MOUSER# 660-RK73B1ETTP200J
2R2: 1K; R_0402_1005Metric; MOUSER# 603-RC0402FR-131KL
2R3: 0R; R_0402_1005Metric; MOUSER#.Var 3.3V(DNP) 5V(791-RMC10JPTH)
2R4, 2R14: 49R9; R_0402_1005Metric; MOUSER# 660-RK73H1ETTP49R9F
2R5: 10K; R_0402_1005Metric; MOUSER# 603-RE0402FRE0710KL
2R6: 0R56 0.25W; R_0805_2012Metric; MOUSER# 652-CRL0805FWR560ELF
2R7: 49K9 0.1W; R_0402_1005Metric; MOUSER# 667-ERJ-2RKF4992X
2R8: 19K1; R_0402_1005Metric; MOUSER# 652-CR0402-FX1912GLF
2R9: 499R; R_0402_1005Metric; MOUSER# 791-RMC1/16SK4990FTH
2R10: 41K2; R_0402_1005Metric; MOUSER# 652-CR0402-FX4122GLF
2R11: 13K3; R_0402_1005Metric; MOUSER# 603-RC0402FR-0713K3P
2R12: 2K; R_0402_1005Metric; MOUSER# 71-CRCW0402-2.0K-E3
2R21: 24K9; R_0402_1005Metric; MOUSER# 708-RMCF0402FT24K9
2R22: 59K; R_0402_1005Metric; MOUSER# 603-RC0402FR-1359KL
2R23, 2R24: 80K6; R_0402_1005Metric; MOUSER# 71-CRCW0402-80.6K-E3
2R25: 3K57; R_0402_1005Metric; MOUSER# 652-CR0402-FX3571GLF
2U1: TLV431ACDBZR; SOT-23-3; MOUSER# 595-TLV431ACDBZR
2U2: TPS23753APW; SOP65P640X120-14N; MOUSER# 595-TPS23753APWR

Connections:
/Ethernet/CT1: 1D1.3; also elsewhere on the board
/Ethernet/CT2: 1D1.4; also elsewhere on the board
/P3: 1D2.3; also elsewhere on the board
/P4: 1D2.4; also elsewhere on the board
/Power/Vss: 1D1.2 (-), 1D2.2 (-), 1R1.2, 2C17.2, 2D5.2 (A2), 2U2.7 (VSS)
/Vdd: 1C6.1, 1D1.1 (+), 1D2.1 (+), 1L1.1, 2C11.1, 2C17.1, 2D5.1 (A1), 2D6.1 (K), 2R21.1, 2U2.8 (VDD1), 2U2.9 (VDD); also elsewhere on the board
/Vin: 2D6.2 (A), 2R23.1; also elsewhere on the board
/Vout: 1C1.1, 1C2.1, 1C4.1, 2C1.2, 2D1.1 (K), 2R2.1, 2R3.1, 2R5.1, 2R10.1; also elsewhere on the board
GND: 1C1.2, 1C2.2, 1C4.2, 1C8.2, 1T1.5, 1T1.6, 2C2.1, 2R11.2, 2U1.3 (A); also elsewhere on the board
GNDPWR: 1C6.2, 1C7.2, 1C8.1, 1T1.2, 2C4.2, 2C7.2, 2C9.2, 2C11.2, 2Q1.3, 2R6.1, 2R22.1, 2R24.2, 2R25.2, 2U2.6 (RTN); also elsewhere on the board
unnamed: 1L1.2, 1T1.3, 2C3.1, 2C4.1, 2R7.1
unnamed: 1T1.1, 2R14.2
unnamed: 2C1.1, 2R1.2
unnamed: 2C2.2, 2D3.3 (K), 2R5.2
unnamed: 2C6.1, 2R8.2
unnamed: 2C8.1, 2R9.2
unnamed: 1T1.7, 1T1.8, 2D1.2 (A), 2R1.1
unnamed: 1T1.4, 2D2.2 (A), 2Q2.3 (D)
unnamed: 2C3.2, 2D2.1 (K), 2R7.2
unnamed: 2D3.2 (A), 2R3.2
unnamed: 2D4.1 (A), 2R14.1
unnamed: 1C7.1, 2C9.1, 2D4.3 (K), 2U2.4 (VC)
unnamed: 2Q1.1, 2R2.2
unnamed: 2Q2.1 (G), 2R4.1
unnamed: 2Q2.2 (S), 2R6.2, 2U2.3 (CS)
unnamed: 2C5.2, 2C6.2, 2R10.2, 2R11.1, 2U1.1 (FB)
unnamed: 2C5.1, 2D3.1 (K), 2Q1.2, 2R8.1, 2U1.2 (K)
unnamed: 2R23.2, 2R25.1, 2U2.12 (APD)
unnamed: 2R24.1, 2U2.13 (BLNK)
unnamed: 1R1.1, 2U2.11 (CLS)
unnamed: 2C8.2, 2Q1.4, 2R12.2, 2U2.1 (CTL)
unnamed: 2R21.2, 2U2.10 (DEN)
unnamed: 2R22.2, 2U2.14 (FRS)
unnamed: 2R4.2, 2U2.5 (GATE)
unnamed: 2C7.1, 2R9.1, 2R12.1, 2U2.2 (VB)

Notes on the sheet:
Vout ${/4c939de5-59ef-438d-9f29-5de1016e5f2f/f9d12477-ea4d-43a2-879f-ca1c6bdc4510/d1e544b5-c030-4490-b5be-d693908662a6:InfoV}@${/4c939de5-59ef-438d-9f29-5de1016e5f2f/f9d12477-ea4d-43a2-879f-ca1c6bdc4510/d1e544b5-c030-4490-b5be-d693908662a6:InfoA}

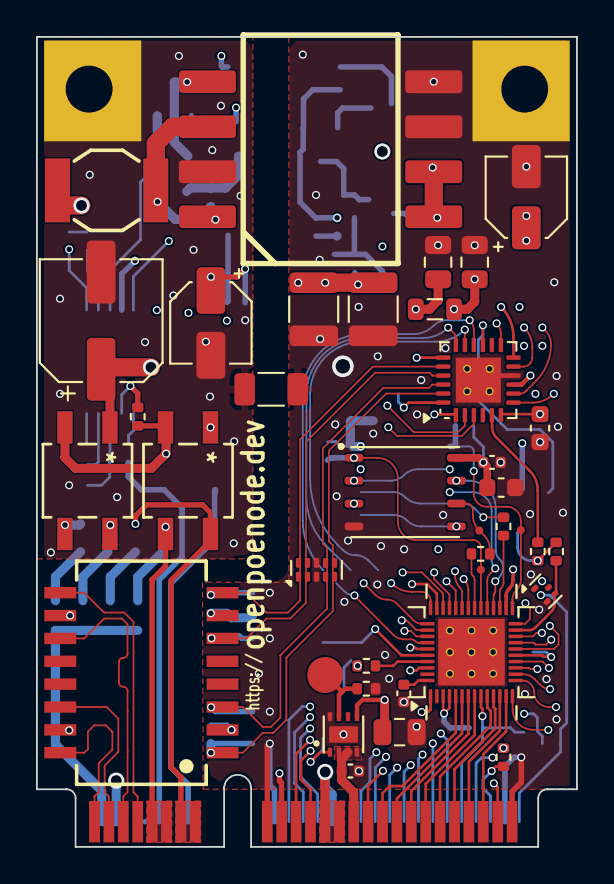
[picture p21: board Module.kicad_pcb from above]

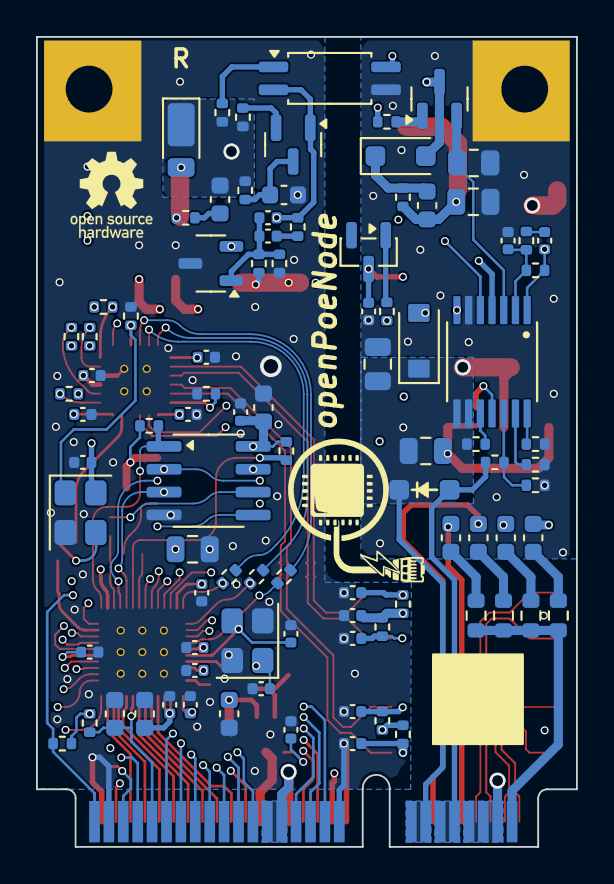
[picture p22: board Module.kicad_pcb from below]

Board: 6 copper layers, 30.0 x 45.0 mm, 132 parts (92 on the bottom side), 112 nets.

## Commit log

2026-01-09 moved serial number barcode away from via
    [Module.kicad_pcb]
2026-01-12 changed MOUSER# for R13 and arranged reference designators on PCB
    [Module.kicad_pcb, Power.kicad_sch]
2026-01-24 updated schematic headers
    [Ethernet.kicad_sch, MCU.kicad_sch, Power.kicad_sch]
2026-01-25 updated Mouser part number for PSRAM
    [MCU.kicad_sch, Module.kicad_pcb]
2026-01-26 all parts geo-renamed
    [Ethernet.kicad_sch, MCU.kicad_sch, Module.kicad_pcb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]
2026-01-26 fixed PSRAM part value
    [MCU.kicad_sch]
2026-01-26 properties cleanup added unique parts ID
    [Ethernet.kicad_sch, MCU.kicad_sch, Module.kicad_pcb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]
2026-01-29 fixed wrong flyback transformer pinout
    [Module.kicad_pcb]
2026-01-29 moved bottom 0402 resistors away from board edge
    [Module.kicad_pcb]
2026-01-29 increased trace width from all goldfinger connector traces to 6mil reduced mask and paste reduction of 1U3 to 1mil
    [Module.kicad_pcb]
2026-01-29 added testpoints to flash/ram signals
    [MCU.kicad_sch, Module.kicad_pcb]
2026-01-29 moved three 0402 resistors away from board edge
    [Module.kicad_pcb]
2026-01-29 added test points for PoE stage
    [Module.kicad_pcb, Module.kicad_sch, Power.kicad_sch]
2026-01-31 fixed 2D4 polarity orientation and footprint
    [Module.kicad_pcb, Power.kicad_sch]
2026-01-31 fixed Flash and PSRAM to MCU pinout mapping added pull-up to Flash CS pin
    [MCU.kicad_sch, Module.kicad_pcb]
2026-02-03 small, cosmetic fixes added project url to front silkscreen
    [Ethernet.kicad_sch, MCU.kicad_sch, Module.kicad_pcb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]
2026-02-20 ESP32 silk screen enhancement added missing part numbers finalized r0.3 work optimized Ethernet ESD diode position added second 22uF bulk updated transformer footprint courtyard enlarged supply curre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
    [Module.kicad_pcb, Module.kicad_sch, Power.kicad_sch]
2026-03-19 added IDAnything
    [Module.kicad_pcb]
2026-04-06 added some LCSC part numbers
    [Ethernet.kicad_sch, MCU.kicad_sch, Module.kicad_sch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]
2026-04-18 added README.md
    [Ethernet.kicad_sch]
2026-04-23 added idle supply current info

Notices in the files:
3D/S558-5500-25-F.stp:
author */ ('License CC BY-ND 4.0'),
